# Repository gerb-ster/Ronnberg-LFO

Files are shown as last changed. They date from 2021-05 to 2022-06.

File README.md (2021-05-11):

# Ronnberg LFO

This is my take on the LFO module designed by Niklas Ronnberg. I’ve changed the range switch with an on-off-on type switch. This way, in the off position, the timing cap consist of a single .001 uF cap, the other 2 positions either add an extra .068uF or 1uF cap. This increases the selectable range quit a bit. I’ve also added a triangle-to-sine converter based on a design by Thomas Henry.

## Status: Finished

- done: first schematic & board design
- done: breadboard and test
- done: design frontpanel
- done: order PCB and build prototype

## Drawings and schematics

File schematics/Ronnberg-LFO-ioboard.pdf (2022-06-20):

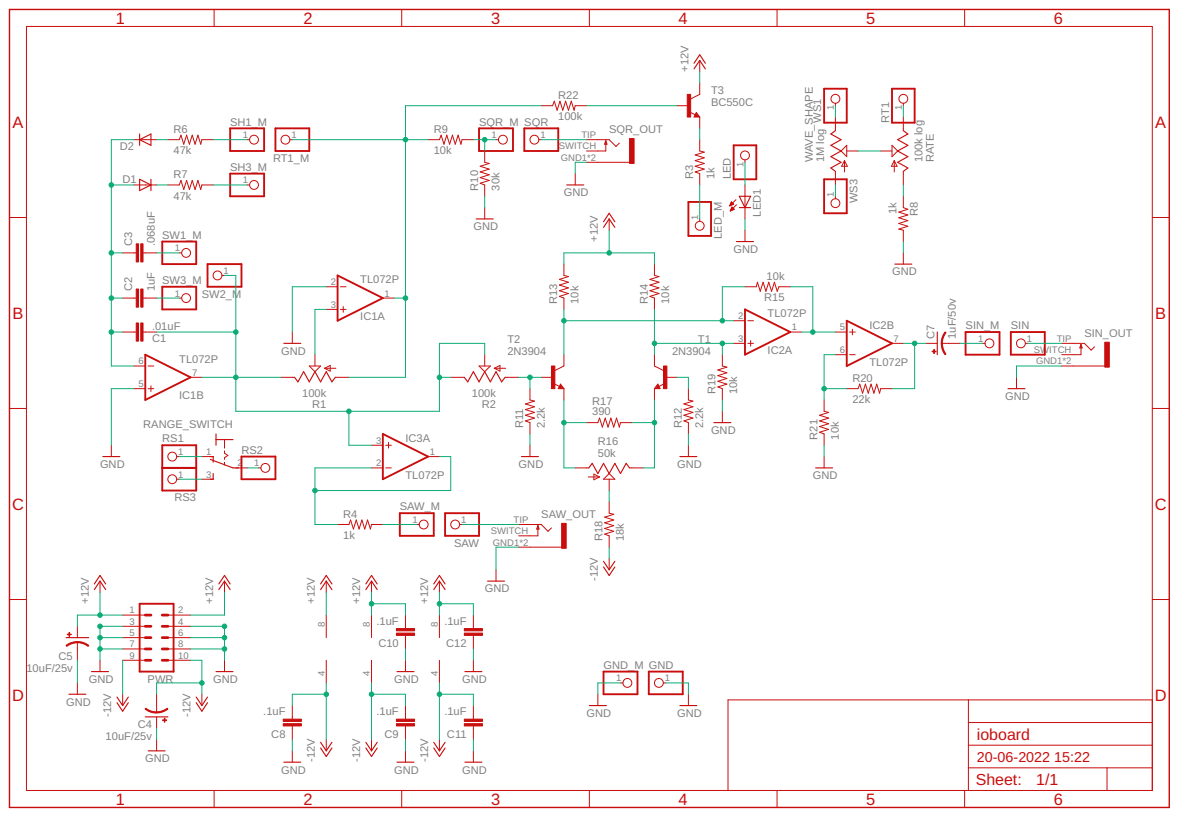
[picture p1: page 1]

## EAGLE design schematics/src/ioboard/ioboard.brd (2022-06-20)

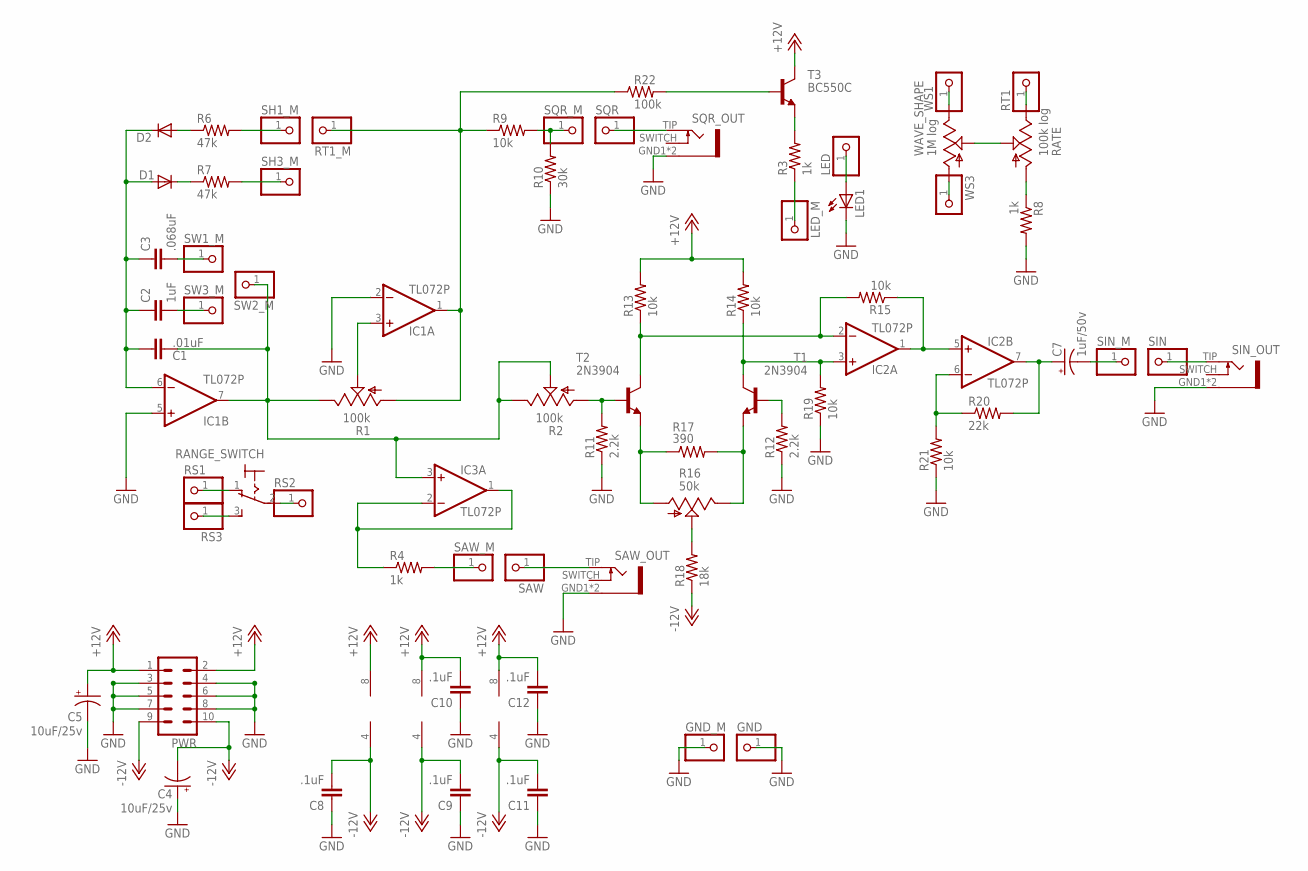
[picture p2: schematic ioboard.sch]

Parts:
C1: .01uF; C050-025X075
C2: 1uF; C050-025X075
C3: .068uF; C050-025X075
C4, C5: 10uF/25v; E2,5-5
C7: 1uF/50v; E2,5-5
C8, C9, C10, C11, C12: .1uF; C025-024X044
D1, D2: 1N4148DO35-7; DO35-7
GND: PINHD-1X1; 1X01
GND_M: PINHD-1X1; 1X01
IC1, IC2, IC3: TL072P; DIL08
LED: PINHD-1X1; 1X01
LED1: LED5MM
LED_M: PINHD-1X1; 1X01
PWR: ML10
R1, R2: 100k; RJ9W
R3, R8: 1k; 0207/10
R4: 1k; 0207/2V
R6, R7: 47k; 0207/10
R9, R13: 10k; 0207/10
R10: 30k; 0207/10
R11, R12: 2.2k; 0207/10
R14, R15, R19, R21: 10k; 0207/2V
R16: 50k; RJ9W
R17: 390; 0207/10
R18: 18k; 0207/10
R20: 22k; 0207/2V
R22: 100k; 0207/10
RANGE_SWITCH: M9040P
RATE: 100k log; EVUF
RS1, RS2, RS3: PINHD-1X1; 1X01
RT1, RT1_M: PINHD-1X1; 1X01
SAW: PINHD-1X1; 1X01
SAW_M: PINHD-1X1; 1X01
SAW_OUT: PJ301BMPJ301BM; PJ301BM
SH1_M, SH3_M: PINHD-1X1; 1X01
SIN: PINHD-1X1; 1X01
SIN_M: PINHD-1X1; 1X01
SIN_OUT: PJ301BMPJ301BM; PJ301BM
SQR: PINHD-1X1; 1X01
SQR_M: PINHD-1X1; 1X01
SQR_OUT: PJ301BMPJ301BM; PJ301BM
SW1_M, SW2_M, SW3_M: PINHD-1X1; 1X01
T1, T2: 2N3904; TO92
T3: BC550C; TO92-CBE
WAVE_SHAPE: 1M log; EVUF
WS1, WS3: PINHD-1X1; 1X01

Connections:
+12V: C5.+, C10.2, C12.2, IC1.8 (V+), IC2.8 (V+), IC3.8 (V+), PWR.1, PWR.2, R13.2, R14.2, T3.C
-12V: C4.-, C8.2, C9.2, C11.2, IC1.4 (V-), IC2.4 (V-), IC3.4 (V-), PWR.9, PWR.10, R18.1
GND: C4.+, C5.-, C8.1, C9.1, C10.1, C11.1, C12.1, GND.1, GND_M.1, IC1.2 (-IN), IC1.5 (+IN), LED1.K (C), PWR.3, PWR.4, PWR.5, PWR.6, PWR.7, PWR.8, R8.2, R10.1, R11.1, R12.1, R19.1, R21.1, SAW_OUT.GND1 (5), SAW_OUT.GND2 (5), SIN_OUT.GND1 (5), SIN_OUT.GND2 (5), SQR_OUT.GND1 (5), SQR_OUT.GND2 (5)
unnamed: RATE.2 (S), WAVE_SHAPE.2 (S)
unnamed: D2.A, R6.1
unnamed: D1.C, R7.1
unnamed: RATE.3 (E), RT1.1
unnamed: R7.2, SH3_M.1
unnamed: C1.1, C2.1, C3.1, D1.A, D2.C, IC1.6 (-IN)
unnamed: C2.2, SW3_M.1
unnamed: R8.1, RATE.1 (A)
unnamed: RANGE_SWITCH.2, RS2.1
unnamed: IC1.3 (+IN), R1.S
unnamed: LED_M.1, R3.1
unnamed: IC1.1 (OUT), R1.A, R9.1, R22.1, RT1_M.1
unnamed: IC2.2 (-IN), R13.1, R15.2, T2.1 (C)
unnamed: C1.2, IC1.7 (OUT), IC3.3 (+IN), R1.E, R2.E, R2.S, SW2_M.1
unnamed: R22.2, T3.B
unnamed: R9.2, R10.2, SQR_M.1
unnamed: R16.S, R18.2
unnamed: C7.+, IC2.7 (OUT), R20.2
unnamed: C7.-, SIN_M.1
unnamed: R2.A, R11.2, T2.2 (B)
unnamed: R16.A, R17.1, T2.3 (E)
unnamed: R16.E, R17.2, T1.3 (E)
unnamed: LED.1, LED1.A
unnamed: R3.2, T3.E
unnamed: R12.2, T1.2 (B)
unnamed: IC2.3 (+IN), R14.1, R19.2, T1.1 (C)
unnamed: IC2.1 (OUT), IC2.5 (+IN), R15.1
unnamed: IC2.6 (-IN), R20.1, R21.2
unnamed: SAW.1, SAW_OUT.TIP (3)
unnamed: SQR.1, SQR_OUT.TIP (3)
unnamed: SIN.1, SIN_OUT.TIP (3)
unnamed: WAVE_SHAPE.3 (E), WS1.1
unnamed: RANGE_SWITCH.3 (S), RS3.1
unnamed: C3.2, SW1_M.1
unnamed: IC3.1 (OUT), IC3.2 (-IN), R4.1
unnamed: WAVE_SHAPE.1 (A), WS3.1
unnamed: R4.2, SAW_M.1
SH1_M: R6.2, SH1_M.1
SLOW_IO: RANGE_SWITCH.1 (O), RS1.1

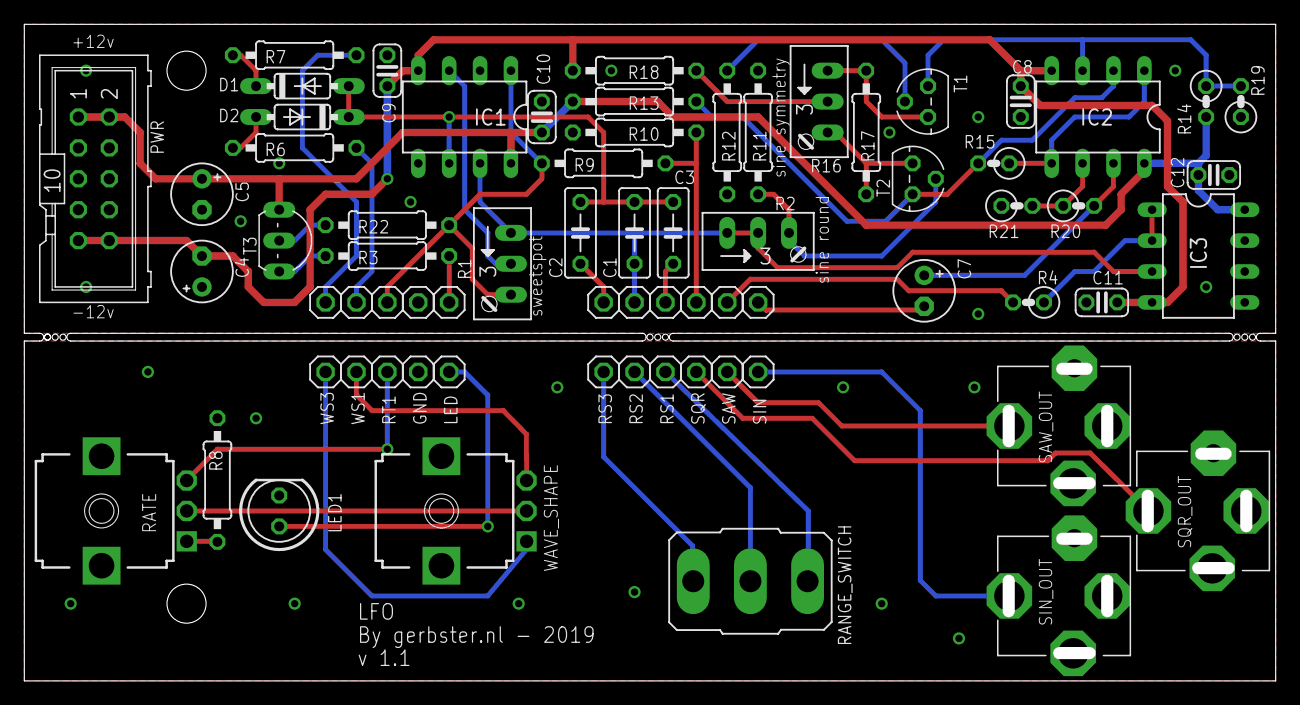
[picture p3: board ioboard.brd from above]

Board: 2 copper layers, 102.9 x 54.0 mm, 70 parts (0 on the bottom side), 42 nets.

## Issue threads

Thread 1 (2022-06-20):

Value of C4/5/7/8/9/10/11/12

KeLaiFu, 2022-06-20:
I've made some PCBs from your layouts and just noticed there's no info for the value of these caps. I would guess 8-12 are 100nf, but not sure on the others. edit...and T3 :)

Thanks

gerb-ster, 2022-06-20:
Yes, you are right, those values where missing. I've updated the schematics! Your guesses were right; T3 should be a BC550C. They are noted in the schematics.

Closed 2022-06-20.

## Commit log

2021-05-06 some files
    [LFO.brd, LFO.sch]
2021-05-07 Added files & structure
    [Ronnberg-LFO-ioboard.GBL, Ronnberg-LFO-ioboard.GBO, Ronnberg-LFO-ioboard.GBP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]
2021-08-06 Updated some schematics and docs
    [Ronnberg-LFO-ioboard.GBL, Ronnberg-LFO-ioboard.GBO, Ronnberg-LFO-ioboard.GBP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]
2021-08-10 Fixed some bugs and updated documentation
    [Ronnberg-LFO-ioboard.XLN, gerber_job.gbrjob]
2022-04-20 Some updates & bugfixes
    [Ronnberg-LFO-ioboard.XLN, gerber_job.gbrjob]
2022-04-22 Fixed schematics & descriptions
    [Ronnberg-LFO-ioboard.XLN, gerber_job.gbrjob]
2022-05-17 Updated Firmware
    [Ronnberg-LFO-ioboard.XLN, gerber_job.gbrjob]
2022-05-18 Updated Faceplates
    [Ronnberg-LFO-ioboard.XLN, gerber_job.gbrjob]
2022-05-18 Fixed issues
    [Ronnberg-LFO-ioboard.XLN, gerber_job.gbrjob]
2022-05-21 Fixed schematics
    [Ronnberg-LFO-ioboard.XLN, gerber_job.gbrjob]
2022-05-28 General updates
    [Ronnberg-LFO-ioboard.GKO, copper_bottom.gbr, copper_top.gbr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]
2022-06-20 Updated schematics with missing values
    [ioboard.brd, ioboard.sch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]
